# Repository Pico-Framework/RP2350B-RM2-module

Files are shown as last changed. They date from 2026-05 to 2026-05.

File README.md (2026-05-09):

# RP2350B-RM2-Module

A compact RP2350B-based wireless module integrating:

- Raspberry Pi RP2350B
- RM2 Wi-Fi/Bluetooth module
- QSPI flash
- QSPI PSRAM
- USB-C
- Onboard voltage-regulator, capable of being disabled for production
- Single-sided design for automated production
- Castellated edges for embedded integration
- SWD debug support

The board is designed as a production-capable embedded module with integrated development convenience.

## Features

- RP2350B MCU
- RM2 wireless module
- 3.3V operation
- QSPI flash
- QSPI PSRAM
- USB device support
- Castellated module form factor
- JLCPCB assembly friendly
- Open hardware

## Status

Early prototype development.

## Repository Contents

- KiCad hardware design files
- Schematics
- PCB layout
- BOM and assembly data
- Production outputs

## Assembly Notes

Current prototype strategy:

- JLCPCB assembly for core board components
- Manual assembly of RM2 and PSRAM components

## License

MIT License

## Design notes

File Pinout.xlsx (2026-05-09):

3V3 | GND | 3V3
GND |  | GND
GPIO0 | GPIO46
GPIO1 | GPIO45 | USB_D+
GPIO2 | GPIO44 | USB_D-
GPIO3 | GPIO43
GND | GPIO42 | RUN
GPIO4 | GPIO41 | BOOTSEL
GPIO5 | GPIO40
GPIO6 | GND | GPIO22
GPIO7 | GPIO39 | GPIO21
GPIO8 | GPIO38
GPIO9 | GPIO37 | RM2_GPIO0
GPIO10 | GPIO36 | RM2_GPIO1
GND | GPIO35 | RM2_GPIO2
GPIO11 | GPIO34
GPIO12 | GPIO33
GPIO13 | GPIO32
GPIO14 | GND
GPIO15 | GPIO31
GND | GPIO30
GPIO16 | GPIO28
GPIO17 | GPIO27
GPIO18 | GPIO26
GPIO19 | GPIO20

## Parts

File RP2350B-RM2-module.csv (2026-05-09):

Id | Designator | Footprint | Quantity | Designation | Supplier and ref
1 | C1, C7, C10, C11, C12, C13, C14, C16, C17, C18, C19, C20, C24 | C_0402_1005Metric | 13 | 100n
2 | C2 | C_0402_1005Metric | 1 | DNF
3 | C3, C4 | C_0402_1005Metric | 2 | 15p
4 | C5, C6, C21 | C_0402_1005Metric_small_pads | 3 | 4.7u
5 | C8, C9 | C_0402_1005Metric | 2 | 4.7u
6 | C15, C22, C23 | C_0805_2012Metric | 3 | 10u
7 | D1 | LED_SK6812MINI-E_3.2x2.8mm_P1.5mm_ReverseMount | 1 | SK6812MINI-E
8 | J1 | JST_SH_BM03B-SRSS-TB_1x03-1MP_P1.00mm_Vertical | 1 | SM03B-SRSS-TB
9 | J2 | Castellated_26_pins_left_side | 1 | Conn_01x26_Socket
10 | J3 | Castellated_26_pins | 1 | Conn_01x26_Socket
11 | J5 | USB_C_Receptacle_XKB_U262-16XN-4BVC11 | 1 | USB_C_Receptacle_USB2.0_16P
12 | L1 | L_pol_2016 | 1 | 3.3u
13 | R1, R4 | R_0402_1005Metric | 2 | DNF
14 | R2, R3 | R_0402_1005Metric | 2 | 0
15 | R5, R13 | R_0402_1005Metric | 2 | 10K
16 | R6, R7, R9 | R_0402_1005Metric | 3 | 1k
17 | R8 | R_0402_1005Metric | 1 | 33
18 | R10, R11, R17 | R_0402_1005Metric | 3 | 27
19 | R12 | R_0402_1005Metric | 1 | 470
20 | R14, R15 | R_0402_1005Metric | 2 | 5.1K
21 | R18, R19 | R_0402_1005Metric | 2 | 50.1K
22 | R20 | R_0402_1005Metric | 1 | 100K
23 | SW1, SW2 | SW_Push_1P1T_NO_Vertical_Wuerth_434133025816 | 2 | SW_Push
24 | TP1 | TestPoint_THTPad_D1.0mm_Drill0.5mm | 1 | TestPoint
25 | U1 | SOIC-8_5.3x5.3mm_P1.27mm | 1 | W25Q128JWSIQ
26 | U2 | SOP-8_3.76x4.96mm_P1.27mm | 1 | APS6404L-SQH-SN
27 | U3 | RP2350-QFN-80-1EP_10x10_P0.4mm_EP3.4x3.4mm_ThermalVias | 1 | RP2350_80QFN
28 | U4 | rpi_rmc20452t | 1 | RM2
29 | U5 | SOT-23-5 | 1 | AP2112K-3.3
30 | Y1 | Crystal_SMD_3225-4Pin_3.2x2.5mm | 1 | ABM8-272-T3

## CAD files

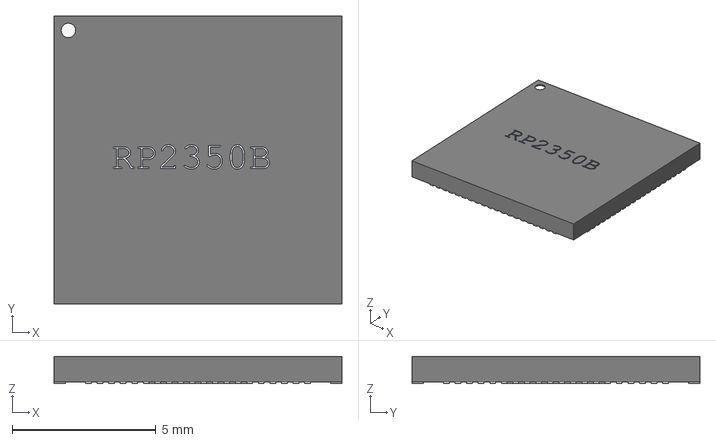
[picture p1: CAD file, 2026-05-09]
RP2350_QFN80.step
10.0 x 10.0 x 0.95 mm

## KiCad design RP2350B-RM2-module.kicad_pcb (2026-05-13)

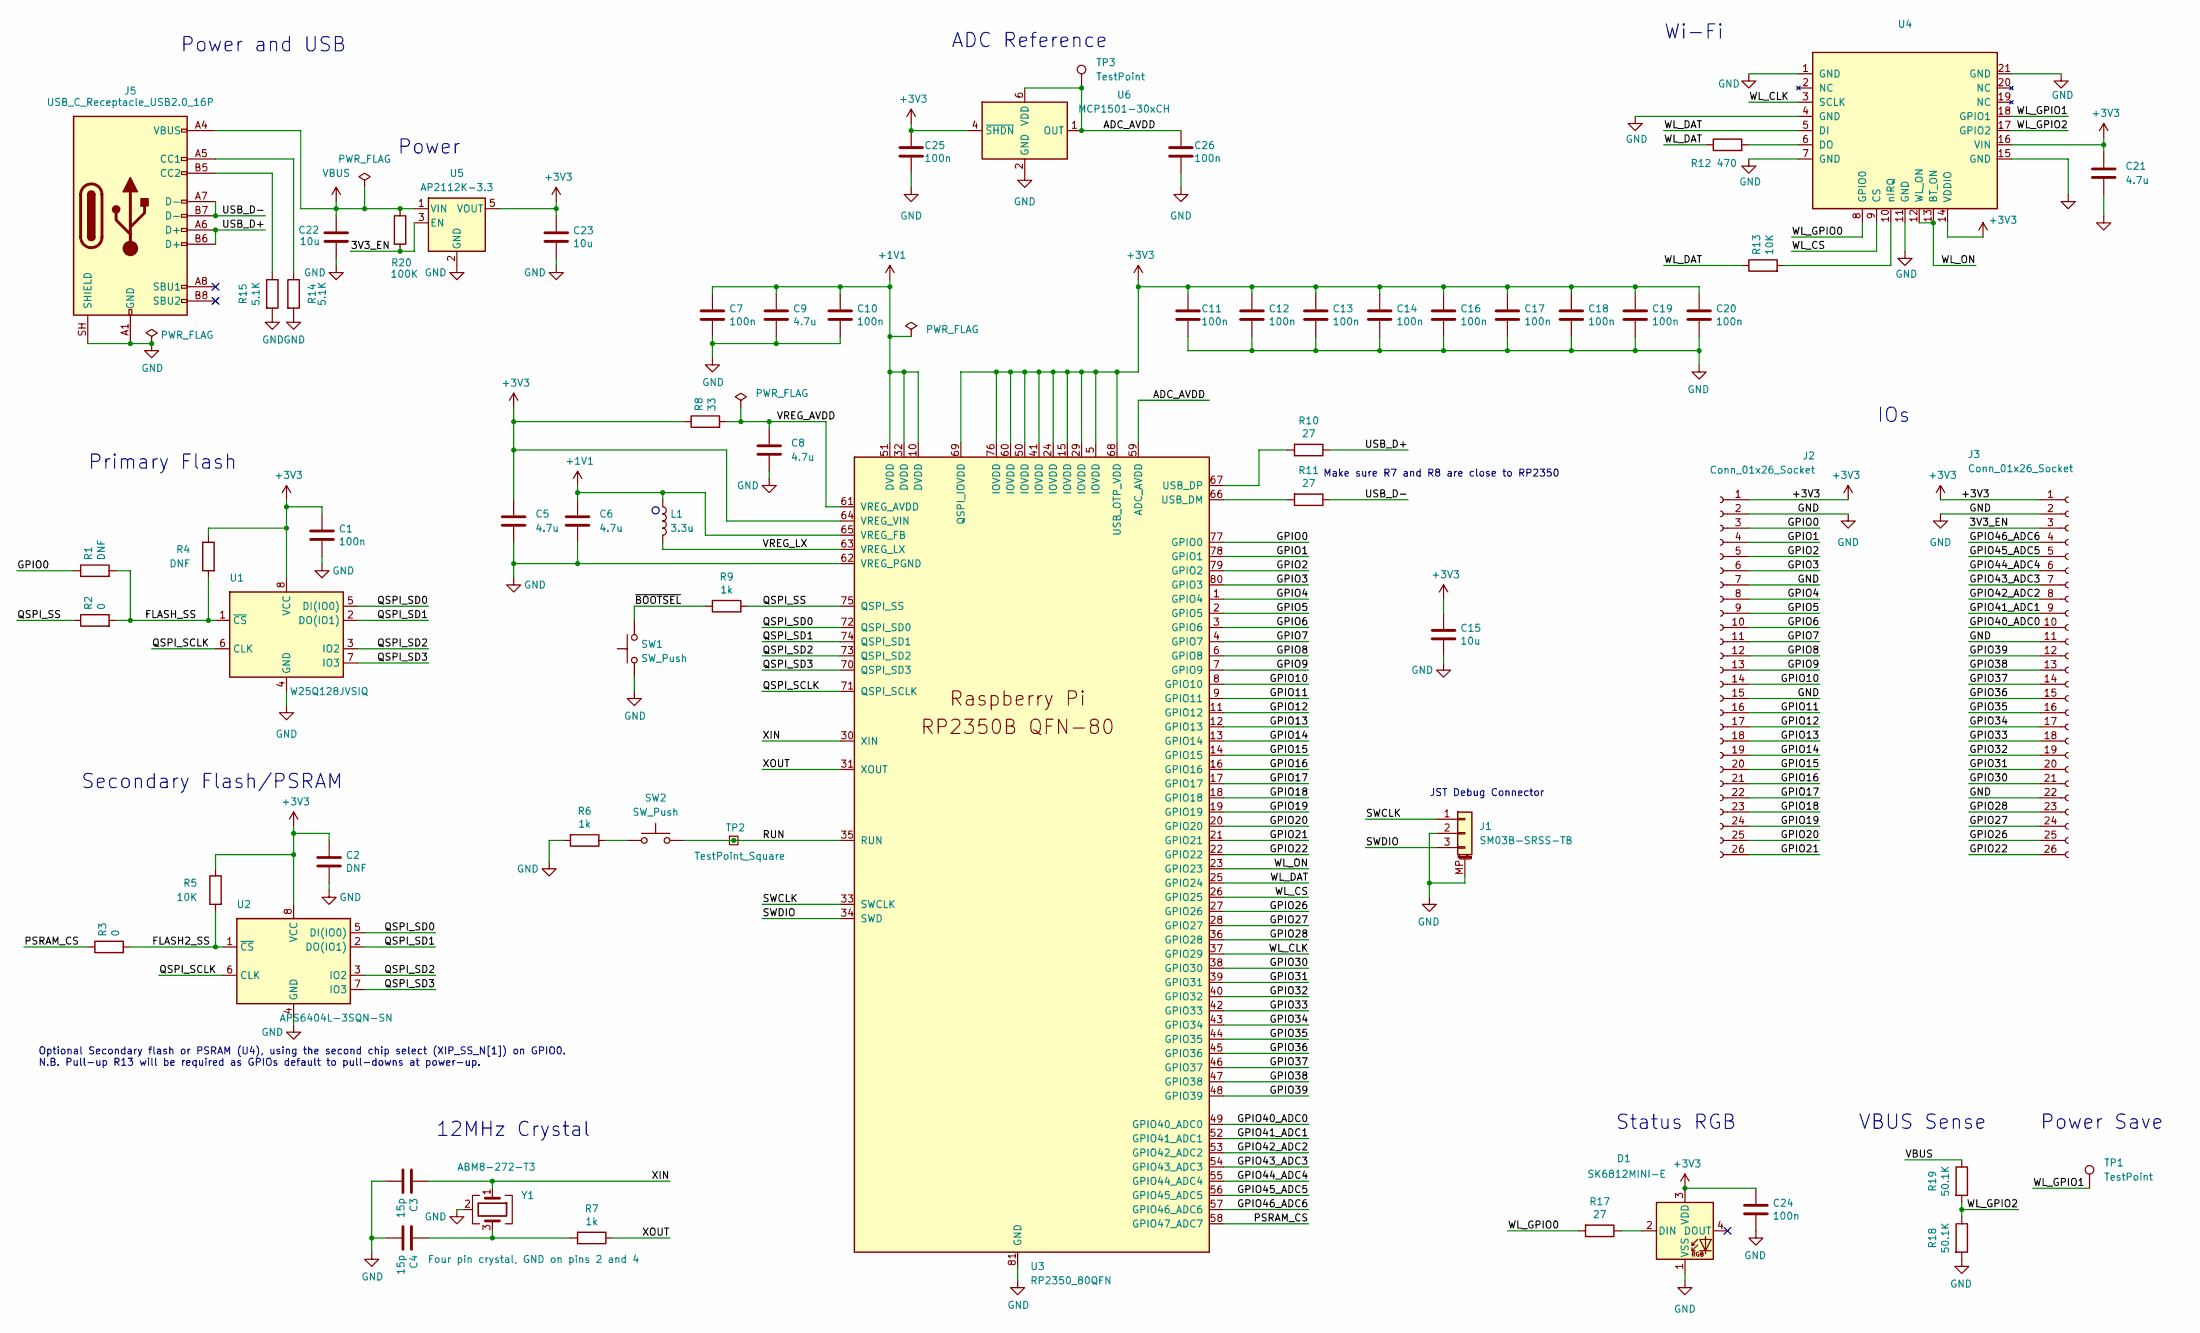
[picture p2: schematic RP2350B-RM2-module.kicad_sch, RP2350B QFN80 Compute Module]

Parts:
C1, C7, C10, C11, C12, C13, C14, C16, C17, C18, C19, C20, C24, C25, C26: 100n; C_0402_1005Metric
C2: DNF; C_0402_1005Metric
C3, C4: 15p; C_0402_1005Metric
C5, C6, C21: 4.7u; C_0402_1005Metric_small_pads
C8, C9: 4.7u; C_0402_1005Metric
C15, C22, C23: 10u; C_0805_2012Metric
D1: SK6812MINI-E; LED_SK6812MINI-E_3.2x2.8mm_P1.5mm_ReverseMount
J1: SM03B-SRSS-TB; JST_SH_BM03B-SRSS-TB_1x03-1MP_P1.00mm_Vertical
J2: Conn_01x26_Socket; Castellated_26_pins_left_side
J3: Conn_01x26_Socket; Castellated_26_pins
J5: USB_C_Receptacle_USB2.0_16P; USB_C_Receptacle_XKB_U262-16XN-4BVC11; Part Number U262-161N-4BVC11; JLCPCB C319148
L1: 3.3u; L_pol_2016
R1, R4: DNF; R_0402_1005Metric
R2, R3: 0; R_0402_1005Metric
R5, R13: 10K; R_0402_1005Metric
R6, R7, R9: 1k; R_0402_1005Metric
R8: 33; R_0402_1005Metric
R10, R11, R17: 27; R_0402_1005Metric
R12: 470; R_0402_1005Metric
R14, R15: 5.1K; R_0402_1005Metric
R18, R19: 50.1K; R_0402_1005Metric
R20: 100K; R_0402_1005Metric
SW1, SW2: SW_Push; SW_Push_1P1T_NO_Vertical_Wuerth_434133025816
TP1: TestPoint; TestPoint_THTPad_D1.0mm_Drill0.5mm
TP2: TestPoint_Square; TestPoint_Pad_1.5x1.5mm
TP3: TestPoint; TestPoint_Pad_D1.5mm
U1: W25Q128JVSIQ; SOIC-8_5.3x5.3mm_P1.27mm; Part Number W25Q128JVSIQ; JLCPCB C113767
U2: APS6404L-3SQN-SN; SOP-8_3.76x4.96mm_P1.27mm; Part Number W25Q128JVSIQ; JLCPCB C113767
U3: RP2350_80QFN; RP2350-QFN-80-1EP_10x10_P0.4mm_EP3.4x3.4mm_ThermalVias; JLCPCB C42415655
U4: <value>; rpi_rmc20452t
U5: AP2112K-3.3; SOT-23-5; Part Number TPAP2112K-3.3TRG1; JLCPCB C3021085
U6: MCP1501-30xCH; SOT-23-6
Y1: ABM8-272-T3; Crystal_SMD_3225-4Pin_3.2x2.5mm

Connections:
+1V1: C6.1, C7.1, C9.1, C10.1, L1.1, U3.10 (DVDD), U3.32 (DVDD), U3.51 (DVDD), U3.65 (VREG_FB)
+3V3: C1.1, C2.1, C5.1, C11.1, C12.1, C13.1, C14.1, C15.1, C16.1, C17.1, C18.1, C19.1, C20.1, C21.1, C23.1, C24.1, C25.1, D1.3 (VDD), J2.1, J3.1, R4.1, R5.1, R8.1, U1.8 (VCC), U2.8 (VCC), U3.5 (IOVDD), U3.15 (IOVDD), U3.24 (IOVDD), U3.29 (IOVDD), U3.41 (IOVDD), U3.50 (IOVDD), U3.60 (IOVDD), U3.64 (VREG_VIN), U3.68 (USB_OTP_VDD), U3.69 (QSPI_IOVDD), U3.76 (IOVDD), U4.14 (VDDIO), U4.16 (VIN), U5.5 (VOUT), U6.4 (~SHDN)
/3V3_EN: J3.3, R20.2, U5.3 (EN)
/ADC_AVDD: C26.1, TP3.1 (1_1), U3.59 (ADC_AVDD), U6.1 (OUT), U6.6 (VDD)
/FLASH2_SS: R3.2, R5.2, U2.1 (~CS)
/FLASH_SS: R1.2, R2.2, R4.2, U1.1 (~CS)
/GPIO0: J2.3, R1.1, U3.77 (GPIO0)
/GPIO1: J2.4, U3.78 (GPIO1)
/GPIO2: J2.5, U3.79 (GPIO2)
/GPIO3: J2.6, U3.80 (GPIO3)
/GPIO4: J2.8, U3.1 (GPIO4)
/GPIO5: J2.9, U3.2 (GPIO5)
/GPIO6: J2.10, U3.3 (GPIO6)
/GPIO7: J2.11, U3.4 (GPIO7)
/GPIO8: J2.12, U3.6 (GPIO8)
/GPIO9: J2.13, U3.7 (GPIO9)
/GPIO10: J2.14, U3.8 (GPIO10)
/GPIO11: J2.16, U3.9 (GPIO11)
/GPIO12: J2.17, U3.11 (GPIO12)
/GPIO13: J2.18, U3.12 (GPIO13)
/GPIO14: J2.19, U3.13 (GPIO14)
/GPIO15: J2.20, U3.14 (GPIO15)
/GPIO16: J2.21, U3.16 (GPIO16)
/GPIO17: J2.22, U3.17 (GPIO17)
/GPIO18: J2.23, U3.18 (GPIO18)
/GPIO19: J2.24, U3.19 (GPIO19)
/GPIO20: J2.25, U3.20 (GPIO20)
/GPIO21: J2.26, U3.21 (GPIO21)
/GPIO22: J3.26, U3.22 (GPIO22)
/GPIO26: J3.25, U3.27 (GPIO26)
/GPIO27: J3.24, U3.28 (GPIO27)
/GPIO28: J3.23, U3.36 (GPIO28)
/GPIO30: J3.21, U3.38 (GPIO30)
/GPIO31: J3.20, U3.39 (GPIO31)
/GPIO32: J3.19, U3.40 (GPIO32)
/GPIO33: J3.18, U3.42 (GPIO33)
/GPIO34: J3.17, U3.43 (GPIO34)
/GPIO35: J3.16, U3.44 (GPIO35)
/GPIO36: J3.15, U3.45 (GPIO36)
/GPIO37: J3.14, U3.46 (GPIO37)
/GPIO38: J3.13, U3.47 (GPIO38)
/GPIO39: J3.12, U3.48 (GPIO39)
/GPIO40_ADC0: J3.10, U3.49 (GPIO40_ADC0)
/GPIO41_ADC1: J3.9, U3.52 (GPIO41_ADC1)
/GPIO42_ADC2: J3.8, U3.53 (GPIO42_ADC2)
/GPIO43_ADC3: J3.7, U3.54 (GPIO43_ADC3)
/GPIO44_ADC4: J3.6, U3.55 (GPIO44_ADC4)
/GPIO45_ADC5: J3.5, U3.56 (GPIO45_ADC5)
/GPIO46_ADC6: J3.4, U3.57 (GPIO46_ADC6)
/PSRAM_CS: R3.1, U3.58 (GPIO47_ADC7)
/QSPI_SCLK: U1.6 (CLK), U2.6 (CLK), U3.71 (QSPI_SCLK)
/QSPI_SD0: U1.5 (DI(IO0)), U2.5 (DI(IO0)), U3.72 (QSPI_SD0)
/QSPI_SD1: U1.2 (DO(IO1)), U2.2 (DO(IO1)), U3.74 (QSPI_SD1)
/QSPI_SD2: U1.3 (IO2), U2.3 (IO2), U3.73 (QSPI_SD2)
/QSPI_SD3: U1.7 (IO3), U2.7 (IO3), U3.70 (QSPI_SD3)
/QSPI_SS: R2.1, R9.1, U3.75 (QSPI_SS)
/RUN: SW2.2, TP2.1 (1_1), U3.35 (RUN)
/SWCLK: J1.1, U3.33 (SWCLK)
/SWDIO: J1.3, U3.34 (SWD)
/USB_D+: J5.A6 (D+), J5.B6 (D+), R10.1
/USB_D-: J5.A7 (D-), J5.B7 (D-), R11.1
/VREG_AVDD: C8.1, R8.2, U3.61 (VREG_AVDD)
/VREG_LX: L1.2, U3.63 (VREG_LX)
/WL_CLK: U3.37 (GPIO29), U4.3 (SCLK)
/WL_CS: U3.26 (GPIO25), U4.9 (CS)
/WL_DAT: R12.1, R13.1, U3.25 (GPIO24), U4.5 (DI)
/WL_GPIO0: R17.2, U4.8 (GPIO0)
/WL_GPIO1: TP1.1 (1_1), U4.18 (GPIO1)
/WL_GPIO2: R18.1, R19.2, U4.17 (GPIO2)
/WL_ON: U3.23 (GPIO23), U4.12 (WL_ON), U4.13 (BT_ON)
/XIN: C3.1, U3.30 (XIN), Y1.1
/XOUT: R7.1, U3.31 (XOUT)
/~BOOTSEL: R9.2, SW1.2
GND: C1.2, C2.2, C3.2, C4.2, C5.2, C6.2, C7.2, C8.2, C9.2, C10.2, C11.2, C12.2, C13.2, C14.2, C15.2, C16.2, C17.2, C18.2, C19.2, C20.2, C21.2, C22.2, C23.2, C24.2, C25.2, C26.2, D1.1 (VSS), J1.2, J1.MP (MountPin), J2.2, J2.7, J2.15, J3.2, J3.11, J3.22, J5.A1 (GND), J5.A12 (GND), J5.B1 (GND), J5.B12 (GND), J5.SH (SHIELD), R6.2, R14.2, R15.2, R18.2, SW1.1, U1.4 (GND), U2.4 (GND), U3.62 (VREG_PGND), U3.81 (GND), U4.1 (GND), U4.4 (GND), U4.7 (GND), U4.11 (GND), U4.15 (GND), U4.21 (GND), U5.2 (GND), U6.2 (GND), U6.3 (GND), U6.5 (GND), Y1.2 (G), Y1.4 (G)
unnamed: C4.1, R7.2, Y1.3
unnamed: D1.2 (DIN), R17.1
unnamed: J5.A5 (CC1), R14.1
unnamed: J5.B5 (CC2), R15.1
unnamed: R6.1, SW2.1
unnamed: R11.2, U3.66 (USB_DM)
unnamed: R10.2, U3.67 (USB_DP)
unnamed: R12.2, U4.6 (DO)
unnamed: R13.2, U4.10 (nIRQ)
VBUS: C22.1, J5.A4 (VBUS), J5.A9 (VBUS), J5.B4 (VBUS), J5.B9 (VBUS), R19.1, R20.1, U5.1 (VIN)

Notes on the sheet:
Optional Secondary flash or PSRAM (U4), using the second chip select (XIP_SS_N[1]) on GPIO0. N.B. Pull-up R13 will be required as GPIOs default to pull-downs at power-up.
Power
IOs
12MHz Crystal
Status RGB
Power and USB
Primary Flash
Power Save
JST Debug Connector
ADC Reference
Make sure R7 and R8 are close to RP2350
Secondary Flash/PSRAM
Wi-Fi
VBUS Sense

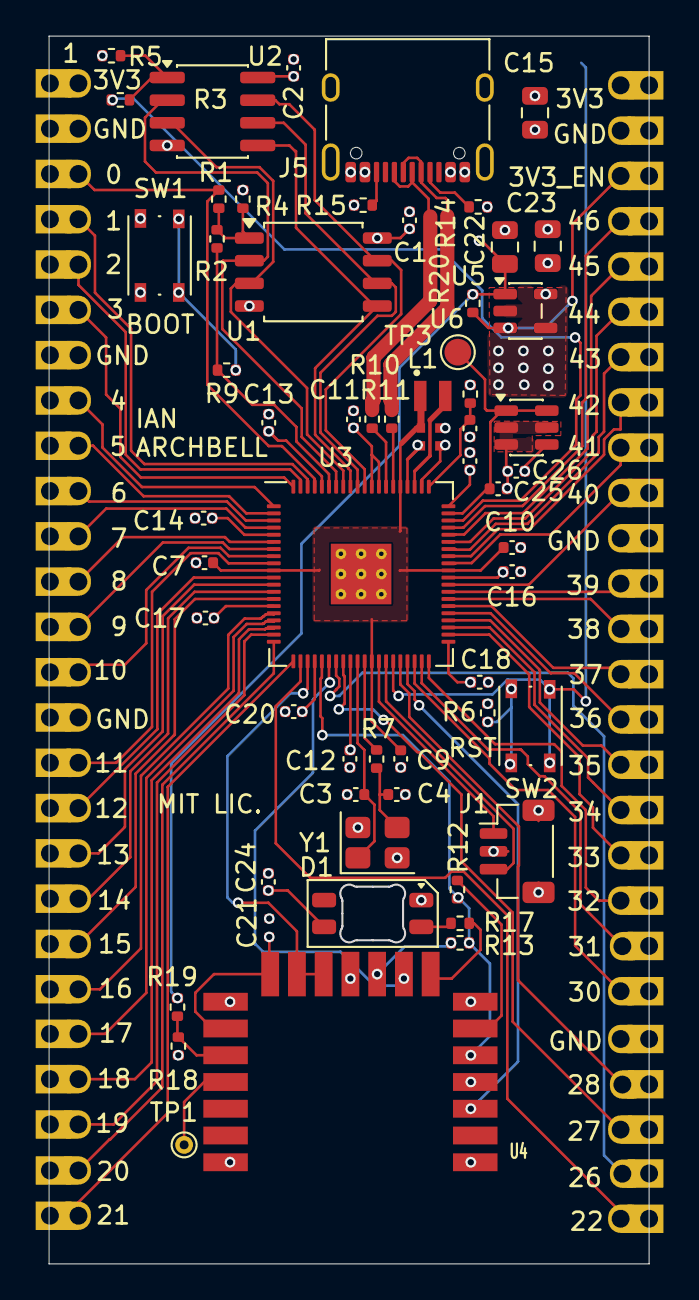
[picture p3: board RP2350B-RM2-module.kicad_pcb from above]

Board: 4 copper layers, 33.7 x 68.8 mm, 63 parts (1 on the bottom side), 84 nets.

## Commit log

2026-05-09 Initial RP2350B RM2 module design
    [Pinout.xlsx, RP2350B-RM2-module.csv, RP2350B-RM2-module.kicad_pcb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]
2026-05-12 clean ERC and DRC
    [RP2350B-RM2-module.kicad_pcb, RP2350B-RM2-module.kicad_sch]
2026-05-12 Changed PSRAM
    [RP2350B-RM2-module.kicad_pcb, RP2350B-RM2-module.kicad_sch]
2026-05-12 Added ADC vref
    [RP2350B-RM2-module.kicad_pcb, RP2350B-RM2-module.kicad_sch]
2026-05-13 Added pin numbering
    [RP2350B-RM2-module.kicad_pcb, RP2350B-RM2-module.kicad_sch]
